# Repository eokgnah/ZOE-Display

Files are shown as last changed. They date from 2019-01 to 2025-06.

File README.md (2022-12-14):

# ZOE CAN ESP32

Bei diesem Projekt handelt es sich um eine Display-Platine zum Auslesen von Fahrzeugdaten (z.B. State of Health, Ladeleistung, Reifendruck) für die Renault ZOE Phase 1 (Q210, R210, R240, Q90, R90, R110, nur bis 2019).

Das Display wird mittels einer 3D-druckbaren Halterung in die Ablage unterhalb des R-Link eingelegt und über den direkt darunterliegenden OBD-Port an den CAN-Bus des Fahrzeugs angeschlossen. Es verwendet einen ESP32-Mikrocontroller mit WLAN-Funktionalität und kann per Webbrowser konfiguriert werden. 

Weitere Informationen und Bilder gibt es im GoingElectric-Forum unter https://www.goingelectric.de/forum/viewtopic.php?t=37914

Platine V5 wird über den USB-Port des R-Link mit Strom versorgt. 

Bei den Platinen V7 und V8 erfolgt die Stromversorgung über den OBD-Port. Hierbei schaltet sich die Platine beim Aufschließen des Fahrzeugs oder Starten eines Ladevorgangs automatisch ein (sobald der CAN-Bus aktiv ist). Nach Abschließen des Fahrzeugs bzw. Beendigung des Ladevorgangs kann sich das Display nach einer konfigurierbaren Zeitdauer auch selbst wieder ausschalten.
Optional kann eine USB-Buchse integriert werden, über welche beispielsweise Mobilgeräte aufgeladen werden können.

Für die Platine V8 existiert eine ausführliche Lötanleitung unter https://github.com/eokgnah/ZOE-Display/blob/master/Platine%20V8/README.md.
Der Aufbau sollte damit auch für Unerfahrene kein allzu großes Problem darstellen.

<pre>
!!!!!!!!!!!!!!!!!!!!!!!!!!!!!!!!!!!!!!!!!!!!!!!!!!!!!!!!!!!!!!!!!!
!!!! OHNE GEWÄHR, ALLES AUF EIGENE GEFAHR, NUR ZU TESTZWECKEN !!!!
!!!!!!!!!!!!!!!!!!!!!!!!!!!!!!!!!!!!!!!!!!!!!!!!!!!!!!!!!!!!!!!!!!
</pre>

## Verwendete Bauteile

- ESP32-Development-Board 38-Pin-Variante (z.B. https://www.berrybase.de/esp32-nodemcu-development-board oder https://www.ebay.de/itm/122795614934 oder https://www.amazon.de/gp/product/B071P98VTG)
- 2,8 Zoll 240 x 320 SPI TFT Panel resistiver Touchscreen (mit Display-Treiber ILI9341, z.B. https://www.ebay.de/itm/284811606229 oder https://www.amazon.de/dp/product/B082QVKT7M oder https://de.aliexpress.com/item/1005002233178546.html [Variante TL9341])
- alternativ mit kapazitivem Touchscreen (Adafruit 1947 mit Display-Treiber ILI9341, z.B. https://www.exp-tech.de/displays/tft/5430/adafruit-2.8-tft-touch-shield-for-arduino-w/capacitive-touch oder https://www.amazon.de/gp/product/B00R3R65C0/ oder https://www.mouser.de/ProductDetail/Adafruit/1947?qs=GURawfaeGuArmJSJoJoDJA%3D%3D)
- SD-Karte (bei resistivem Touchscreen) bzw. microSD-Karte (bei kapazitivem Touchscreen)
- optional GPS-Modul NEO-6M (z.B. https://www.berrybase.de/u-blox-neo-6m-gps-ttl-empfaenger-inkl.-antenne oder https://www.amazon.de/gp/product/B088LR3488 oder https://www.ebay.de/itm/265640015319)
- Kleinteile (siehe Ordner zur jeweiligen Platinen-Version)

## Verbindungen mit resistivem Touchscreen
<pre>
ESP32 Dev Board Pinout

Wohin           Bezeich.       ESP32 Pins       Bezeich.    Wohin

                            3V3         GND
                            EN          G23     MOSI        Display,Touch,SD
                ST          G36         G22
                            G39         G1      (TX)
                            G34         G3      (RX)
                (CAN2 RX)   G35         G21     CS          Touch
                (CAN2 TX)   G32         GND
                HR          G33         G19     MISO        Display,Touch,SD
                            G25         G18     SCLK        Display,Touch,SD
GPS-Modul       GPS TX      G26         G5 
GPS-Modul       GPS RX      G27         G17     CAN TX      OBD-Anschluss
BUZZER+                     G14         G16     CAN RX      OBD-Anschluss
                POWER OFF   G12         G4      RST         Display
                            GND         G0      (BOOT)
SD              CS          G13         G2      DC          Display
                (Flash)     G9          G15     CS          Display
                (Flash)     G10         G8      (Flash)
                (Flash)     G11         G7      (Flash)
                            5V          G6      (Flash)
</pre>                    
RX und TX gibt den Pin an, mit dem es verbunden werden muss. GPS TX muss also auf den Pin
TX am GPS Modul! 

CAN2 ist derzeit experimentell. 

ST = Screen Turn, ST=1 (verbinden mit 3V3) -> Bildschirm um 180 Grad gedreht

HR = Helligkeitsregelung, kann einen Transistor ansteuern, über den die LED-Hintergrundbeleuchtung des Displays gedimmt werden kann.

POWER OFF = Ausschalt-Pin für die Stromversorgung über den OBD-Port

## Verbindungen mit kapazitivem Touchscreen
<pre>
ESP32 Dev Board Pinout

Wohin           Bezeich.       ESP32 Pins       Bezeich.    Wohin

                            3V3         GND
                            EN          G23     SPI MOSI    Display
                ST          G36         G22     I²C SCL     Display
                            G39         G1      (TX)
                            G34         G3      (RX)
                (CAN2 RX)   G35         G21 
                (CAN2 TX)   G32         GND
Display         HR          G33         G19     SPI MISO    Display
Display         I²C SDA     G25         G18     SPI SCLK    Display
GPS-Modul       GPS TX      G26         G5
GPS-Modul       GPS RX      G27         G17     CAN TX      OBD-Anschluss
BUZZER+                     G14         G16     CAN RX      OBD-Anschluss
                POWER OFF   G12         G4      RST         Display
                            GND         G0      (BOOT)
Display         CARDCS      G13         G2      DC          Display
                (Flash)     G9          G15     CS          Display
                (Flash)     G10         G8      (Flash)
                (Flash)     G11         G7      (Flash)
                            5V          G6      (Flash)
</pre>                    
RX und TX gibt den Pin an, mit dem es verbunden werden muss. GPS TX muss also auf den Pin
TX am GPS Modul! 

CAN2 ist derzeit experimentell. 

ST = Screen Turn, ST=1 (verbinden mit 3V3) -> Bildschirm um 180 Grad gedreht

HR = Helligkeitsregelung, an Pin GPIO33 liegt ein PWM Signal an, welches über Pin D5 am Display
(neben CARDCS) die Regelung der Displayhelligkeit erlaubt. Achtung: Die Lötbrücke #5 auf der 
Displayplatine muss hierfür gesetzt werden.

POWER OFF = Ausschalt-Pin für die Stromversorgung über den OBD-Port
                    
## Allgemein
-  Beim Betrieb des resistiven Displays mit 3,3 V sollte der Jumper J1 am Display gesetzt (verbunden) werden (Ausschalten
des Spannungsreglers des Displays, sonst sinken die 3,3 V auf irgendwas unter 3 V). Der Touch IRQ Pin bleibt leer.
- Das Display mit kapazitivem Touchscreen erhält 5 V Versorgungsspannung. Falls das verwendete Display keine IOREF-Lötbrücke besitzt bzw. diese auf 5 V gesetzt wurde, muss eine geeignete Maßnahme vorgesehen werden, um die Spannungspegel am I²C-Bus auf max. 3,3 V zu begrenzen (das Display zieht die Leitungen nämlich mit 10-kΩ-Pull-Up-Widerständen gegen 5 V).

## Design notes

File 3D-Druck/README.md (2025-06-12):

Die Versionen V6 sind für die Platine V5, mit Loch für ein USB-Kabel zur Stromversorgung.
Die Versionen V7 sind für die Platinen V7 oder V8, ohne selbiges Loch.

Damit das Teil in der Ablage der ZOE gut hält und nicht herumrutscht, sollte umlaufend ein ca. 5 x 5 mm dicker Schaumstoffstreifen angeklebt werden.

Zum Drucken sollte ein Material mit guter Hitzebeständigkeit verwendet werden, z.B. ABS. Meine aus PLA gedruckte Version hatte sich nach einem Jahr im Auto stark verformt :-)

Hier einige 3D-Druck-Dienstleister:
- https://www.3ddesign24.de/
- https://fdm-druckservice.de
- https://3-dreams.de

Aktuell habe ich noch zwei 3D-gedruckte Teile für das resistive Display aus grauem ABS abzugeben, welche ich bei 3ddesign24.de bestellt habe. Schaumstoffstreifen für den sicheren Halt in der ZOE habe ich bereits rundherum angebracht. Bei Interesse gerne schreiben an kepppfeff@outlook.de.

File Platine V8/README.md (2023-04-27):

# Platine V8 — Lötanleitung

von Michi (Kontakt: kepppfeff@outlook.de oder im GoingElectric-Forum: kepppfeff-ZOE)

<pre>
!!!!!!!!!!!!!!!!!!!!!!!!!!!!!!!!!!!!!!!!!!!!!!!!!!!!!!!!!!!!!!!!!!
!!!! OHNE GEWÄHR, ALLES AUF EIGENE GEFAHR, NUR ZU TESTZWECKEN !!!!
!!!!!!!!!!!!!!!!!!!!!!!!!!!!!!!!!!!!!!!!!!!!!!!!!!!!!!!!!!!!!!!!!!
</pre>

## Benötigte Bauteile

Zusätzlich zu den unter https://github.com/eokgnah/ZOE-Display/blob/master/README.md aufgelisteten Hauptkomponenten und dem 3D-Druck werden die folgenden Bauteile benötigt. 

#### Module & Halbleiter
- U2: Spannungsregler OKI-78SR-5/1.5-W36-C oder vergleichbar (Ausgang 5 V, 1500...2000 mA)
  - Bezugsquellen: z.B. https://www.tme.eu/de/details/amsr2-7805jz/dc-dc-wandler/aimtec/ oder https://www.reichelt.de/dc-dc-wandler-oki-78sr-8-w-5-v-1500-ma-sil-single-oki515w36c-p140735.html oder https://www.voelkner.de/products/1038830/
  - Falls keine USB-Buchse an die Platine angeschlossen werden soll, kann stattdessen auch ein schwächerer (günstigerer) Spannungsregler verwendet werden, z.B. LC78_05-0.5 oder vergleichbar (Ausgang 5 V, 500 mA)
- U3: Spannungsregler LC78_03-0.5 oder LMO78_03-0.5 oder vergleichbar (Ausgang 3,3 V, 500 mA)
  - Bezugsquellen: z.B. https://www.tme.eu/de/details/amsro-783.3-nz/dc-dc-wandler/aimtec/ oder https://www.reichelt.de/dc-dc-wandler-1-65-w-3-3-v-500-ma-sil-lmo78-03-0-5-p242833.html oder https://www.voelkner.de/products/1038822/
  - Stattdessen kann auch der interne Spannungsregler des ESP32-Boards verwendet werden, dieser ist jedoch nicht so effizient und sorgt für zusätzliche Aufheizung des Mikrocontrollers, was evtl. dessen Lebensdauer verringert.
- Q1: P-Kanal-MOSFET IRFU9024N
- IC4: CAN-Transceiver MCP2562 (DIP8)
- D3, D4: Schottky-Dioden 1N5817
- T1: NPN-Transistor BC547C (nur bei Verwendung des kapazitiven Displays)
- T4: PNP-Transistor BC327-25
- T5, T6: NPN-Transistoren BC547C

#### Passive Bauelemente
- R1: Widerstand 100 kΩ ± 50 % (nur bei Verwendung des kapazitiven Displays)
- R3: Widerstand 1,5 kΩ ± 5 % (nur bei Verwendung des resistiven Displays mit eingebautem Transistor, siehe weiter unten) bzw. Widerstand 5,1 Ω ± 5 % (nur bei Verwendung des resistiven Displays ohne eingebauten Transistor, siehe weiter unten)
- R4: Widerstand 15 kΩ ± 5 % (nur bei Verwendung des kapazitiven Displays der alten Version, siehe weiter unten)
- R5: Widerstand 120 Ω ± 10 %
- R6: Widerstand 15 kΩ ± 5 %
- R7: Widerstand 15 kΩ ± 5 % (nur bei Verwendung des kapazitiven Displays der alten Version, siehe weiter unten)
- R8: Widerstand 100 kΩ ± 5 %
- R9: Widerstand 470 kΩ ± 10 %
- R10, R11: Widerstände 1,2 MΩ ± 5 %
- R12: Widerstand 470 kΩ ± 5 %
- R13: Widerstand 47 kΩ ± 5 %
- C1: Elektrolyt-Kondensator 10 μF, min. 10 V
- C2, C3, C4: Keramik-Kondensatoren 100 nF
- C5: Elektrolyt-Kondensator 10 μF, min. 25 V
- C6: Elektrolyt-Kondensator 22 μF, min. 6,3 V

#### Steckverbinder & Elektromechanik
- OBD-Stecker (z.B. https://kds-online.de/de/obd-minitools-modular-system-stecker-e.html oder https://www.tme.eu/de/details/a-obd-e2/gehause-sonstiges-zubehor/minitools/sep-a-obd-e2/)
- Piezo-Summer, mit Kabeln oder für Printmontage (RM 7,6 mm)
- IC-Sockel DIP8 (für MCP2562)
- USB-Buchse (optional)
- Schraubklemmblock 3-polig (RM 5 mm) für Stromversorgung (12 V Eingang, 5 V Ausgang)
- Schraubklemmblock 2-polig (RM 5 mm) für CAN-Bus
- Kabel zum Anschluss von OBD-Stecker und ggf. USB-Buchse
- Stiftleisten (für GPS-Modul, resistives Display und ggf. als Abstandshalter)

## Grundlegendes Vorgehen

Wer bereits Platinen bestückt hat, kann diesen Abschnitt gerne überspringen ;-)

Zum Zusammenbau des ZOE-Displays benötigt ihr Folgendes:
- Lötkolben und Lötzinn, Lötspitzen-Reinigungstool (feuchter Schwamm, Spiralwolle etc.)
- Seitenschneider bzw. Vornschneider
- Spitzzange
- Abisolierzange
- Schlitz-Schraubendreher
- Heißklebepistole und -sticks, alternativ 2-Komponenten-Kleber oder ähnliches
- Eventuell (falls ihr etwas falsch verlötet habt): Entlötsaugpumpe, Entlötlitze etc.

Bei dieser Platine werden alle Bauteile in Durchsteckmontage (Printmontage) bestückt. Die grundlegende Vorgehensweise, um ein Bauteil einzulöten, ist Folgende:

1. Anschlussdrähte des Bauteils zurechtbiegen (falls nötig).
2. Bauteil von der Seite der Platine, auf der der Bestückungsdruck für das Bauteil angebracht ist, durch die entsprechenden Kontaktlöcher stecken.
3. Platine umdrehen und die herausragenden Drähte (bzw. Metallstifte) nacheinander mit den Leiterbahnen verlöten. Zum Löten sollte man in der Regel zuerst den Lötkolben an die beiden zu verlötenden Metallteile halten (hier Draht und Leiterplattenkontakt), sodass die Lötspitze *beide* Teile erhitzt. Direkt anschließend gibt man das Lötzinn hinzu, welches sich nun kegelförmig (nicht kugelförmig :D) um den Draht verteilen sollte. 
4. Alle überstehenden Drähte abschneiden, und zwar möglichst direkt an der Lötstelle.

Hierbei kann man entweder alle Bauteile einzeln nacheinander durchstecken und verlöten oder auch mehrere auf einmal. Damit die Bauteile während des Lötens nicht nach unten aus der Platine herausrutschen können, macht es Sinn, mit den flachsten Bauteilen anzufangen und sich nach und nach zu den höchsten Bauteilen vorzuarbeiten. Im Idealfall liegt die Platine dann immer auf dem Bauteil auf, welches als Nächstes angelötet werden soll. 

Wenn ihr noch nie Bauteile auf eine Platine gelötet habt, ist es sicherlich hilfreich, vorher mal ein entsprechendes Tutorial-Video z.B. auf Youtube anzuschauen.

## Hinweise zum resistiven Touchscreen

Bei Verwendung des Displays mit resistivem Touchscreen werden die Widerstände R1, R4 und R7 sowie der Transistor T1 nicht benötigt.

Falls ihr das Display mit resistivem Touchscreen verwendet, solltet ihr zunächst prüfen, ob dieses einen eingebauten Transistor für die LED-Hintergrundbeleuchtung eingebaut hat oder nicht. Nur wenn ein Transistor eingebaut ist, könnt ihr die Helligkeit des Displays steuern.
Von der Versionsbezeichnung des Displays hängt dies scheinbar nicht ab; ich habe schon Bilder von V1.1 und V1.2 jeweils sowohl mit und ohne Transistor gesehen! Ihr müsst also tatsächlich den Transistor auf der Display-Platine suchen. Es handelt sich um ein kleines schwarzes Bauteil mit drei Pins, welches auf der Platine mit **Q1** beschriftet sein muss (es gibt eventuell ein gleich aussehendes Bauteil, welches anders beschriftet ist, das ist aber kein Transistor, sondern ein Spannungsregler). 
- Falls euer Display *zwei* kleine schwarze Bauteile mit je drei Pins hat, von denen eines mit U1 und eines mit Q1 beschriftet ist, dann habt ihr ein Display *mit* eingebautem Transistor. **In diesem Fall muss für R3 ein 1,5-kΩ-Widerstand eingesetzt werden. Außerdem sollte die Lötbrücke SJ5 gesetzt werden, damit die Display-Helligkeit vom ESP32 gesteuert werden kann.**
- Falls euer Display nur *ein* kleines schwarzes Bauteil mit drei Pins hat, dann hat das Display *keinen* Transistor eingebaut. **In diesem Fall muss für R3 ein 5,1-Ω-Widerstand eingesetzt werden (anders als auf dem Bestückungsdruck angegeben!). Die Lötbrücke SJ5 muss offen bleiben, da sonst der ESP32 Schaden nehmen kann!**

In der Regel müsst ihr auf euer Display noch eine 4-polige Stiftleiste für die Anschlüsse der SD-Karte einlöten. Hier darauf achten, dass ihr diese möglichst gerade montiert, damit das Display später perfekt auf die Platine passt. Am Besten gelingt dies, wenn ihr das Display zum Anlöten der 4-polige Stiftleiste lose in die entsprechenden Kontaktlöcher der (noch unbestückten) Platine legt.

Das resistive Display besitzt zudem eine Lötbrücke (J1), die ggf. gesetzt werden muss. Hierzu bitte den Abschnitt „Hinweise zu den Lötbrücken zur Auswahl der Stromversorgung“ beachten.

## Hinweise zum kapazitiven Touchscreen

Bei Verwendung des Displays mit kapazitivem Touchscreen wird der Widerstand R3 nicht benötigt.

Falls ihr das Display mit kapazitivem Touchscreen verwendet, solltet ihr zunächst prüfen, ob ihr die alte oder die neue Version des Displays besitzt. Kleine Anmerkung am Rande: Auf den beiden folgenden Fotos wurde jeweils rechts die 6-polige ISP-Buchse abgelötet, dies ist jedoch bei der Platine V8 nicht erforderlich!

### Alte Version
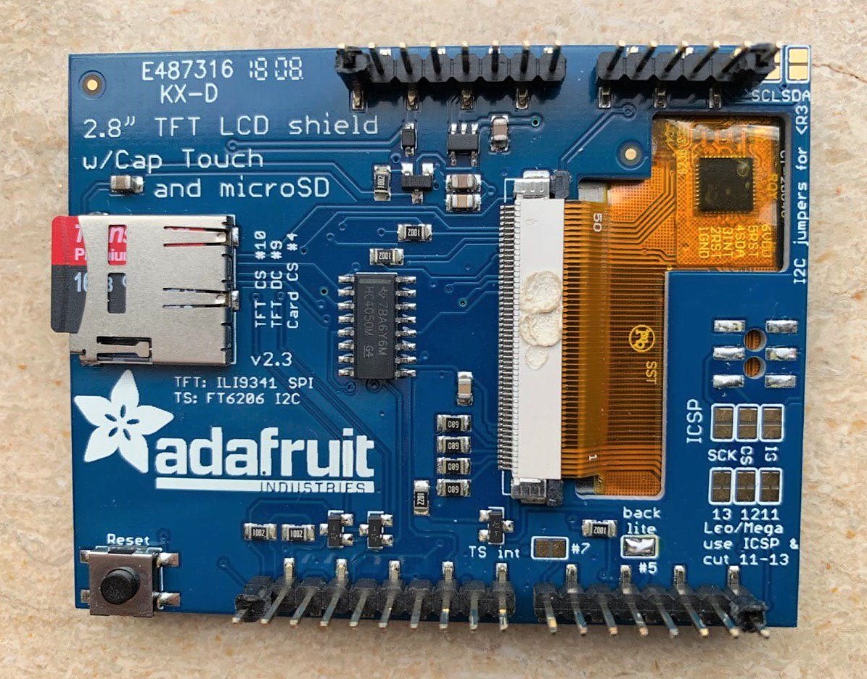
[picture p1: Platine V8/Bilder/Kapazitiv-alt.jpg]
Alte Version

Hier müsst ihr lediglich die Lötbrücke „backlight #5“ setzen, wie im Foto zu sehen, damit die LED-Hintergrundbeleuchtung gedimmt werden kann. Die Lötbrücken „13“, „12“ und „11“ sind bei dieser Version bereits standardmäßig (über feine Leiterbahnen) gesetzt.

**Bei der Bestückung der Platine sind die beiden 15-kΩ-Widerstände R4 und R7 zwingend erforderlich, da ohne diese der ESP32 eine zu hohe Spannung vom Display abbekommt.**

### Neue Version
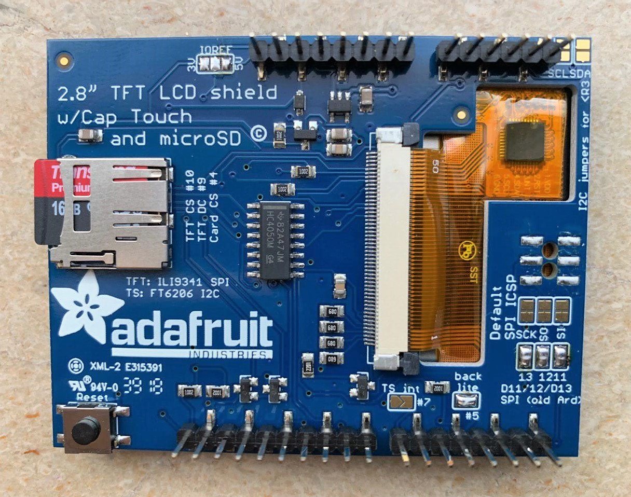
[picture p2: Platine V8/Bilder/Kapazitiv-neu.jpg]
Neue Version

Wie man sieht, gibt es hier die zusätzliche Lötbrücke IOREF. Diese müsst ihr (anders als im Foto!) auf 3,3 V setzen, also das mittlere und das linke (mit „3V“ beschriftete) Pad mit einem Tropfen Lötzinn verbinden. 

**Bei der Bestückung der Platine sollten dann die beiden 15-kΩ-Widerstände R4 und R7 weggelassen werden.**

Außerdem müsst ihr die Lötbrücken „backlight #5“, „13“, „12“ und „11“ setzen (wie im Foto zu sehen).

## Hinweise zu den Lötbrücken zur Auswahl der Stromversorgung

Der 3,3-V-Spannungsregler **U3** (LC78_03-0.5 oder ähnlich) ist nicht unbedingt erforderlich, da alternativ auch der interne (lineare) Spannungsregler des ESP32 verwendet werden kann. Zur Auswahl zwischen diesen beiden Varianten dienen die Lötbrücken SJ2, SJ3 und SJ4.

### Falls die Platine mit Spannungsregler U3 bestückt wird, ...

... werden ESP32, GPS-Modul und resistives Display vom Spannungsregler U3 mit 3,3 V versorgt. 

**Hierzu muss die Lötbrücke SJ4 gesetzt werden. Bei Verwendung des resistiven Displays muss zusätzlich dessen Lötbrücke J1 gesetzt werden.**

Wenn die Platine nur über den USB-Port des ESP32 betrieben wird (z.B. zum Flashen), ist das kapazitive Display bei dieser Schaltungsvariante nicht in Betrieb! Wer dies ändern möchte, kann zusätzlich die Lötbrücke SJ2 setzen, allerdings wird dadurch bei Versorgung über den OBD-Port die Spannungswandlung ineffizienter, da der interne Spannungsregler des ESP32 ständig „mitläuft“.

### Falls der Spannungsregler U3 weggelassen wird, ...

... werden ESP32, GPS-Modul und resistives Display vom Spannungsregler U2 mit 5 V versorgt. Alle drei nutzen dann ihre internen linearen Spannungsregler, um die Spannungsdifferenz zu verbraten. 

**Hierzu müssen die Lötbrücken SJ2 und SJ3 gesetzt werden. Bei Verwendung des resistiven Displays muss dessen Lötbrücke J1 offen bleiben.**

## Platine löten
#### Schritt 1: Lötbrücken setzen

Als erstes solltet ihr alle benötigten Lötbrücken setzen. 

- SJ1 bestimmt über die Ausrichtung des Bildschirms. Bei Verwendung des 3D-gedruckten ZOE-Einlegers sollte diese Lötbrücke für das resistive Display normalerweise auf die Seite mit dem „S“ und für das kapazitive Display auf die Seite mit der „1“ gesetzt werden. An diese Lötbrücke kommt man auch später noch ganz gut dran, sodass es kein Problem ist, wenn sie falsch gesetzt wurde.
- Wie ihr SJ2, SJ3 und SJ4 setzen müsst, findet ihr unter „Hinweise zu den Lötbrücken zur Auswahl der Stromversorgung“.
- SJ5 sollte nur bei Verwendung eines resistiven Displays mit eingebautem Transistor gesetzt werden.

#### Schritt 2: Widerstände und Dioden

Als nächstes kommen die flachen Bauteile dran. Bei Widerständen ist die Polarität egal, bei den Dioden ist der Strich, welcher den Minuspol kennzeichnet, auf dem Bestückungsdruck eingezeichnet. 

#### Schritt 3: IC-Sockel

Damit der CAN-Transceiver-IC (IC4) nicht durch die Hitze Schaden nimmt, wird er nicht auf die Platine gelötet, sondern nur ein passender Sockel, in den der IC später eingesteckt wird. Die Einbaurichtung des ICs kann über eine einseitige Einkerbung kontrolliert werden, welche auf dem Bestückungsdruck eingezeichnet ist.

#### Schritt 4: Keramik-Kondensatoren

Nun sind C2, C3 und C4 an der Reihe. Es können Keramik-Kondensatoren mit 2,5 mm oder 5 mm Rastermaß verwendet werden. Die Polarität ist egal. 

#### Schritt 5: Piezo-Summer

Falls ein Piezo-Summer für Printmontage verbaut wird, sollte dieser je nach Abmessungen jetzt oder etwas später eingelötet werden. Bei einigen Piezo-Summern muss die Polarität beachtet werden (z.B. wenn die Beinchen verschieden lang sind, das längere ist dann Plus), bei anderen nicht.

#### Schritt 6: Stiftleiste für GPS-Modul

Als Nächstes wird eine Stiftleiste eingelötet, auf die später das GPS-Modul montiert werden kann. Das GPS-Modul selbst sollte jetzt noch nicht mit angelötet werden, da es die Anschlüsse für das kapazitive Display teilweise verdecken würde. Je nach GPS-Modul wird eine Stiftleiste mit 4 oder 5 Pins benötigt. Es empfiehlt sich, die Metallstifte etwas zu kürzen, damit sie später nicht so weit herausstehen.

Inzwischen sollte die Platine ungefähr so aussehen:

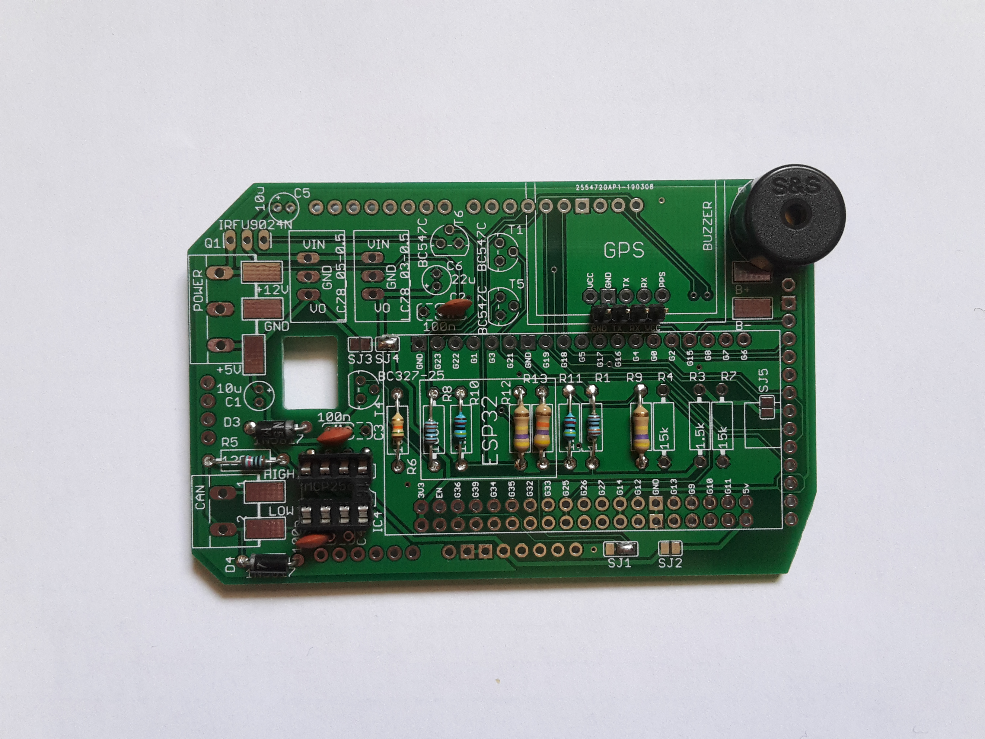
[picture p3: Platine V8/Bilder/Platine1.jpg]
Platine


#### Schritt 7: Transistoren

Jetzt sind die bipolaren Transistoren T1, T4, T5, T6 und der MOSFET Q1 an der Reihe. Bei den bipolaren Transistoren muss jeweils der mittlere Pin vorsichtig etwas zurechtgebogen werden. Die Einbaurichtung dürfte selbsterklärend sein. Der MOSFET muss so herum eingebaut werden, dass die Beschriftung zum Rand der Platine zeigt (und die Metallfläche entsprechend in Richtung der Kabelanschlüsse). 

#### Schritt 8: Schraubklemmblöcke

Nun werden die 3-polige Schraubklemme für die Stromversorgung und die 2-polige Schraubklemme für den CAN-Bus eingelötet.

#### Schritt 9: ESP32

Die Platine ist kompatibel zu zwei verschieden großen ESP32-Boards (mit dem selben Pinout), daher ist die eine Lochreihe doppelt vorhanden. 

Bei günstigen ESP32-Boards sind oft die Stiftleisten nicht ganz gerade eingelötet, dann müsst ihr diese noch etwas zurechtbiegen, um sie in die Kontaktlöcher der Platine zu bekommen.

Damit der ESP32 nachher in der perfekten Höhe (und gerade) montiert ist, bietet es sich an, auf die vier äußersten Pins jeweils als Abstandshalter ein Plastikteil einer Stiftleiste draufzuschieben. Hierzu aus einer vierpoligen Stiftleiste alle Metallstifte herausziehen und anschließend das Plastikteil in seine vier Einzelteile zerbrechen. Am Ende sollte es dann so aussehen (hier sind zusätzlich die Abstandshalter des resistiven Touchdisplays zu sehen, beim kapazitiven werden hingegen keine benötigt):

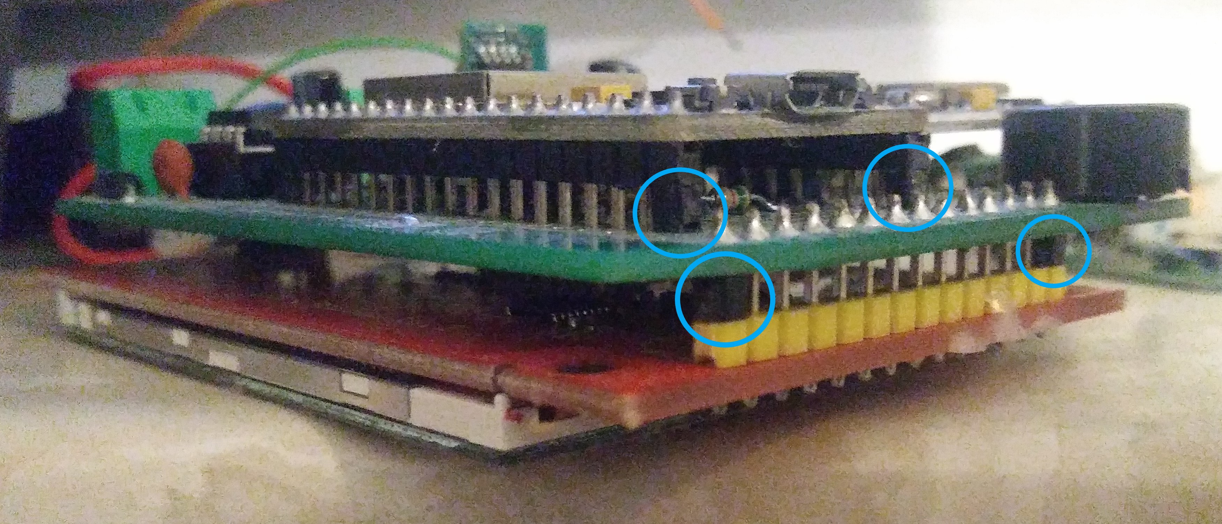
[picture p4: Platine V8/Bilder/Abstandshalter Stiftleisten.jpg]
Abstandshalter


#### Schritt 10: 3,3-V-Spannungsregler

Der 3,3-V-Spannungsregler kommt in das mit „LC78_**03**-0.5“ beschriftete Rechteck. Einbaurichtung beachten! In der Regel sollte die Bauteilbeschriftung in Richtung des POWER-Schraubklemmblocks zeigen. Bei Unsicherheit am Besten im Datenblatt nachschauen, auf der Platine ist der Eingang mit VIN und der Ausgang mit VO beschriftet. 
Falls der Spannungsregler LMO78_03-0.5 verwendet wird (wie im gleich folgenden Foto), sollte dieser eventuell ein wenig gekippt eingebaut werden, da er sonst etwas zu weit in Richtung des Kondensators C6 übersteht, sodass dieser nicht mehr richtig passt.

#### Schritt 11: Elektrolyt-Kondensatoren

Bei den Elkos (C1, C5 und C6) muss auf die Polarität geachtet werden. Der Pluspol ist durch einen längeren Draht, der Minuspol durch einen weißen Strich auf dem Gehäuse gekennzeichnet.

#### Schritt 12: 5-V-Spannungsregler

Der 5-V-Spannungsregler gehört in das mit „LC78_**05**-0.5“ beschriftete Rechteck. Einbaurichtung beachten! Bei Unsicherheit am Besten im Datenblatt nachschauen, auf der Platine ist der Eingang mit VIN und der Ausgang mit VO beschriftet.

Anschließend sollte die Platine ungefähr so aussehen:

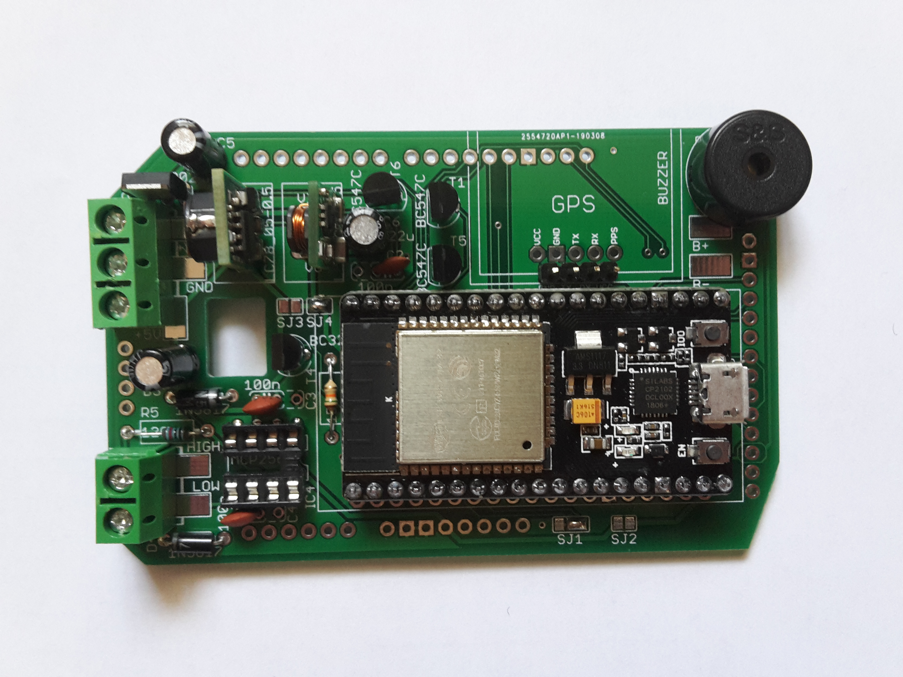
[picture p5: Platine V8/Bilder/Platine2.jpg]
Platine


#### Schritt 13: Display

Bevor ihr Display und Platine zusammenfügt, kontrolliert nochmal, ob alle Lötstellen gut aussehen und ob ihr am Display alle erforderlichen Lötbrücken gesetzt habt, denn ihr kommt anschließend nicht mehr dran! 

Beim kapazitiven Display empfehle ich, dieses erstmal in den 3D-gedruckten Einleger zu setzen (microSD-Karte einlegen und Schutzfolie abziehen!), anschließend die Platine darauf zu platzieren und erst dann, im „lose eingebauten Zustand“, beides zu verlöten. 

Beim resistiven Display ist dieses Vorgehen nicht erforderlich, hier bietet es sich stattdessen an, wieder vier Plastikteile einer Stiftleiste als Abstandshalter zu nutzen. Achtet darauf, dass der SD-Karten-Halter nicht mit von der Platine abstehenden Drähten in Berührung kommt. Zur Sicherheit bietet es sich an, den SD-Karten-Halter mit Kaptonband, Tesafilm oder ähnlichem zu überkleben. 

#### Schritt 14: GPS-Modul

Als Nächstes wird das GPS-Modul auf die zuvor eingelötete Stiftleiste gelötet.

#### Schritt 15: IC einsetzen

Zu guter Letzt wird der CAN-Transceiver-IC in den zuvor eingelöteten Sockel gesteckt. Ausrichtung beachten! Bei „fabrikfrischen“ ICs müssen vorher meist noch die Beinchen etwas nach innen gebogen werden. 

## Verkabelung

Die Drähte zur USB-Buchse, zum OBD-Stecker und zum Piezo-Summer (falls einer mit Kabeln verwendet wird) können auf drei verschiedene Arten an der Platine angeschlossen werden: Durch Anschrauben in angelötete Schraubklemmblöcke, über die SMD-Lötpads oder durch direktes Einlöten der Kabel in die Löcher für die Schraubklemmblöcke. 

Die Beschriftung der Anschlüsse befindet sich jeweils an den SMD-Lötpads, die direkt an die zugehörigen Schraubklemmen angrenzen.

#### USB-Buchse

Um die USB-Buchse in den 3D-gedruckten Einleger zu bekommen, müssen zunächst die beiden Montagepins des Buchsengehäuses etwas gekürzt werden. Anschließend die vier Anschlusspins (Masse, D+, D- und +5 V) nach hinten umbiegen und darauf achten, dass sie nicht mit dem Buchsengehäuse in Berührung kommen. 

An Masse (GND) und +5 V lötet ihr Drähte an, die dann an der Platine angeschlossen werden können. Achtet darauf, dass durch das Lötzinn keine Verbindung mit dem Buchsengehäuse hergestellt wird.

Die beiden Datenleitungen (die mittleren Pins) können im einfachsten Fall kurzgeschlossen werden, dies entspricht der EU-standardisierten Signalisierung eines USB-Ladegeräts. Hierzu einfach die beiden Drähte etwas zur Mitte biegen und mit einem Tropfen Lötzinn verbinden (wieder darf keine Verbindung zum Buchsengehäuse entstehen). Manche USB-Geräte akzeptieren diese Signalisierung allerdings nicht und laden nur langsam. Um die USB-Buchse für solche Geräte kompatibel zu machen, müsst ihr eventuell statt der Kurzschlussmethode bestimmte Spannungen mittels Widerständen an die Datenleitungen anlegen. Mehr Infos dazu findet ihr z.B. hier: http://dh2mic.darc.de/files/usb-adapter-v12.pdf

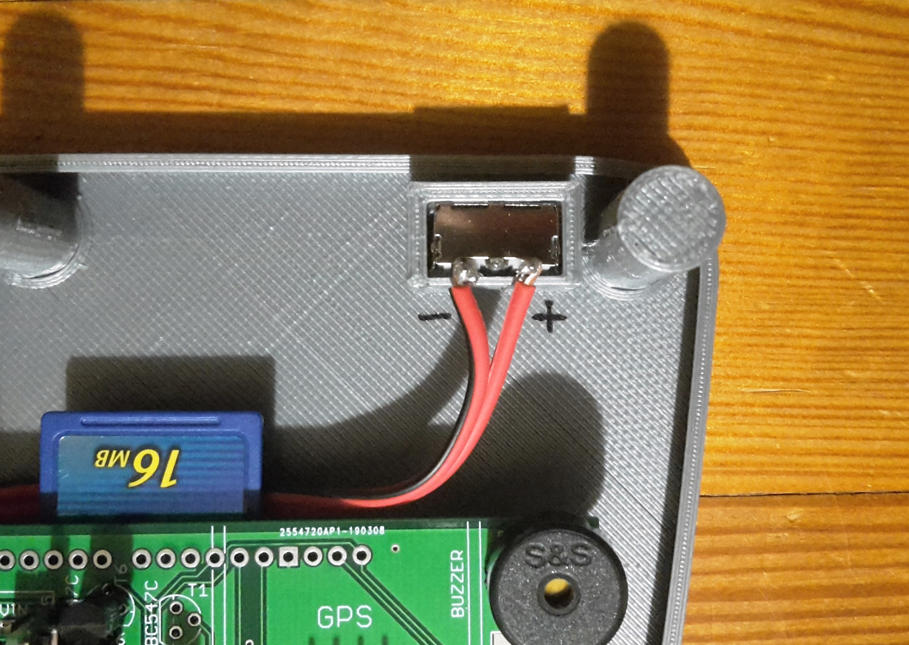
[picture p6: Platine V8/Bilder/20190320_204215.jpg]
USB-Buchse


Zum Schluss noch alles mit Heißkleber, 2-Komponentenkleber o.ä. versiegeln, damit kein Kurzschluss entstehen kann und die USB-Buchse nicht herausrutscht.

#### OBD-Stecker

Die Belegungen einer OBD2-Schnittstelle findet ihr hier: https://commons.wikimedia.org/wiki/File:OBD2-Buchse-Stecker-Belegung.jpg

Vier Pins werden benötigt: Fahrzeugmasse (GND) und +12 V zur Stromversorgung sowie CAN High und CAN Low zur Datenübertragung. 

Achtung: Den Lötkolben nicht zu lange an die Metallstifte des OBD-Steckers halten, da sonst das Plastik drumherum aufweicht, wodurch der Metallstift sich womöglich leicht verdreht oder verschiebt. Alternativ können die Metallstifte zum Anlöten der Drähte aus dem Steckergehäuse herausgenommen und anschließend wieder eingesetzt werden. Die oben verlinkten OBD-Stecker sind nur zusammengesteckt und die Stifte werden von einer eingeklipsten Plastikkappe gehalten.

Wenn ihr den 3D-gedruckten ZOE-Einleger verwendet, müsst ihr die Kontaktstifte des OBD-Steckers zur Seite umbiegen (bzw. die unbenutzten abschneiden oder entfernen), da diese sonst zu weit herausstehen. Das sollte dann etwa so aussehen. 

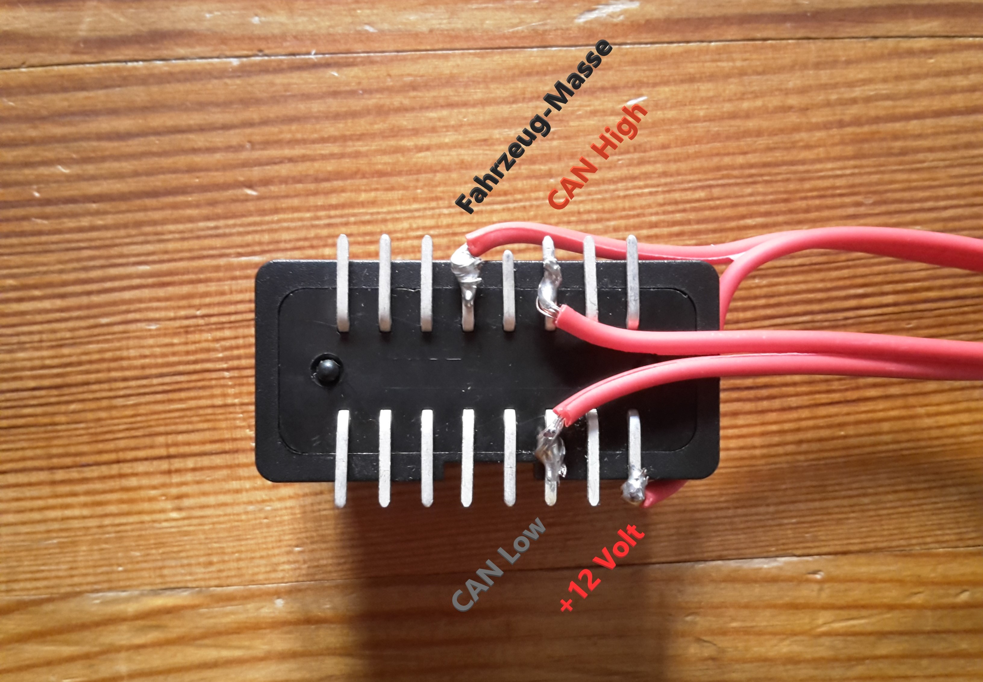
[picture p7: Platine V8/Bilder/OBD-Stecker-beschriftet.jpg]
OBD-Stecker


Anschließend sollten die Lötstellen unbedingt noch z.B. mit Heißkleber oder Schrumpfschläuchen umhüllt werden, damit kein Kurzschluss entstehen kann und die Drähte nicht mit der Zeit (z.B. durch Vibrationen) abbrechen können.

#### Schraubklemmblöcke

Um die Drähte gut in den Schraubklemmblöcken befestigen zu können, sollten die Enden jeweils verdrillt und mit dem Lötkolben verzinnt werden. Wer über das entsprechende Equipment verfügt, kann (und soll) natürlich stattdessen Aderendhülsen verwenden. 

Wer eine USB-Buchse verwendet, muss zwei GND-Drähte in eine Schraubklemme zwängen. Hierzu sollten diese beiden Drähte zusammen verzinnt bzw. zusammen in eine Aderendhülse gecrimpt werden.

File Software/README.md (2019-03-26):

## Software

Anleitung von Erich (eokgnah)

<pre>
!!!!!!!!!!!!!!!!!!!!!!!!!!!!!!!!!!!!!!!!!!!!!!!!!!!!!!!!!!!!!!!!!!
!!!! OHNE GEWÄHR, ALLES AUF EIGENE GEFAHR, NUR ZU TESTZWECKEN !!!!
!!!!!!!!!!!!!!!!!!!!!!!!!!!!!!!!!!!!!!!!!!!!!!!!!!!!!!!!!!!!!!!!!!
</pre>

1. Holt euch die Arduino-IDE: 
https://www.arduino.cc/en/Main/Software

2. Macht die IDE bereit für den ESP32: 
https://randomnerdtutorials.com/installing-the-esp32-board-in-arduino-ide-windows-instructions/

3. Kontrolliert die Einstellungen und installiert auf Eurem neuen ESP32 zum Initialisieren den „bare minimum“-Sketch aus den Beispielen (COM-Port kann bei Euch ggf. ein anderer sein).

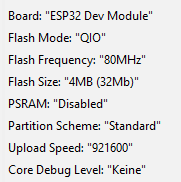
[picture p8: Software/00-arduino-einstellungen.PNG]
Einstellungen der Arduino-IDE


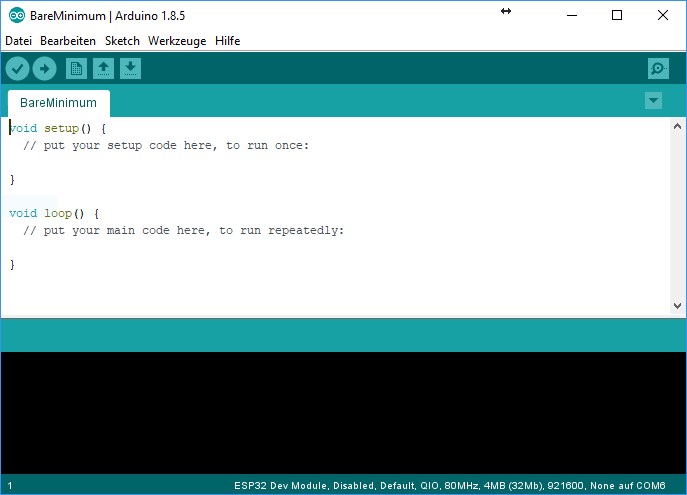
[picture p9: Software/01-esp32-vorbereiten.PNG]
Bare-Minimum-Sketch


Wenn das alles sauber durchgelaufen ist, dann geht es weiter.

4. Holt Euch die „Flash Download Tools (ESP8266 & ESP32)“ von espressif: 
https://www.espressif.com/en/support/download/other-tools

5. Holt Euch das ZOE-Display-Binary (oben in der Ordnerstruktur die entsprechende Datei auswählen oder direkt über den Link https://github.com/eokgnah/ZOE-Display/raw/master/Software/CAN-ESP32.ZOE.esp32-v2.075.bin).

6. Startet die „Flash Download Tools (ESP8266 & ESP32)“, wählt den ESP32 aus und stellt ihn wie folgt ein (COM-Port kann bei Euch ggf. ein anderer sein):

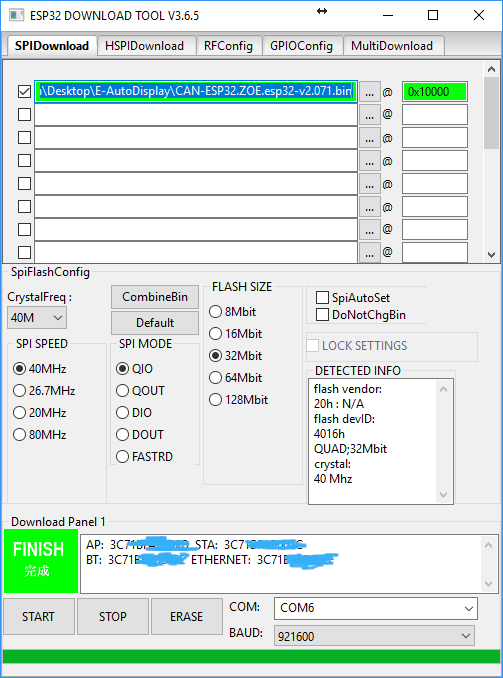
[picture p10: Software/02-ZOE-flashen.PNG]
Einstellungen des Flash Download Tools


7. Auf „START“ drücken und ihn flashen lassen.

8. Wenn er fertig ist, dann könnt Ihr beim ESP mal auf Reset drücken oder ihn kurz vom USB-Strom nehmen, damit er bootet.

9. Es sollte nun ein offener WLAN-Accesspoint (Name so etwas wie „ESP_12BA5C“ oder „ZOE“) bei Euch erschienen sein. 

10. Mit dem WLAN verbinden und auf die IP „192.168.4.1“ mit dem Browser gehen und dann könnt Ihr alles von dort aus über den Browser weiter konfigurieren.

Das alles geht auch nur mit dem ESP32 alleine.
Damit es „sinnvoll“ funktioniert ist es natürlich von Vorteil, wenn Ihr das Display, die SD-Karte, GPS und das CAN-Interface mit anschließt.  

Neuere Updates kommen dann per WLAN „over the air“.
Diese beschriebene Vorgehensweise ist nur ein einziges Mal am Anfang nötig. Danach braucht Ihr keinen PC mehr.

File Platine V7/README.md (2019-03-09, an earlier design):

## Platine V7

von Michi (kepppfeff-ZOE)

<pre>
!!!!!!!!!!!!!!!!!!!!!!!!!!!!!!!!!!!!!!!!!!!!!!!!!!!!!!!!!!!!!!!!!!
!!!! OHNE GEWÄHR, ALLES AUF EIGENE GEFAHR, NUR ZU TESTZWECKEN !!!!
!!!!!!!!!!!!!!!!!!!!!!!!!!!!!!!!!!!!!!!!!!!!!!!!!!!!!!!!!!!!!!!!!!
</pre>

Diese Version funktioniert mit dem kapazitiven Display einwandfrei und passt auch in den 3D-Druck-Einleger.

Das resisitve Display funktioniert technisch auch, allerdings passt die Platine damit nicht in den 3D-Druck-Einleger!

### Allgemeine Hinweise zur Bestückung

- Es können nur Keramikkondensatoren mit 2,5 mm Rastermaß verwendet werden, obwohl auf der Platine jeweils ein zusätzliches Pad für 5 mm Rastermaß vorhanden ist. Denn diese Pads ist nicht angeschlossen!
- Bei den beiden Spannungsreglern ist leider auf dem Bestückungsdruck nicht ersichtlich, welcher wohin gehört. Der 5-V-Spannungsregler muss auf die Seite in Richtung ESP32, der 3,3-V-Spannungsregler auf die Seite in Richtung Anschlussbuchsen.
- Ein 3,3-V-Spannungsregler ist nicht unbedingt erforderlich, da alternativ auch der interne Spannungsregler des ESP32 genutzt werden kann. Falls die Platine mit 3,3-V-Spannungsregler bestückt wird, muss die Lötbrücke SJ4 gesetzt werden; andernfalls müssen die Lötbrücken SJ2 und SJ3 gesetzt werden.
- Der MOSFET (Q1) muss so herum eingebaut werden, dass die Beschriftung in Richtung Spannungsregler zeigt.

### Bei Verwendung des kapazitives Displays

- Die Bauteile R1, R2, R3, R14 sowie T1, T2 und T3 werden nicht benötigt.
- Beim Display müssen die Lötbrücken „backlight“, „13“, „12“ und „11“ gesetzt werden.
- Falls ein Display der neusten Version mit IOREF-Lötbrücke zum Einsatz kommt, sollte diese Lötbrücke auf 3,3 V („3V“) gesetzt werden. Die Widerstände R4 und R7 werden dann nicht benötigt.
- Ich empfehle, das Display erst dann anzulöten, wenn Platine und Display bereits lose im 3D-gedruckten Einleger platziert sind. Ansonsten wird es wahrscheinlich sehr schwierig, diese hineinzubekommen.

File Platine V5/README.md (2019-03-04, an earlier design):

# Platine V5

von erich (eokgnah)

<pre>
!!!!!!!!!!!!!!!!!!!!!!!!!!!!!!!!!!!!!!!!!!!!!!!!!!!!!!!!!!!!!!!!!!
!!!! OHNE GEWÄHR, ALLES AUF EIGENE GEFAHR, NUR ZU TESTZWECKEN !!!!
!!!!!!!!!!!!!!!!!!!!!!!!!!!!!!!!!!!!!!!!!!!!!!!!!!!!!!!!!!!!!!!!!!
</pre>

Im Zip-Archiv befinden sich die Gerber-Dateien zur Herstellung der Platine (z.B. bei https://jlcpcb.com/).

Diese Platine wird über die USB-Buchse des R-Link versorgt. Alternativ kann ein externer Spannungsregler von 12 V auf 5 V genutzt werden, um über die OBD-Buchse versorgt zu werden. In diesem Fall sollte ein manueller Ein-/Ausschalter vorgeschaltet werden, da das Display sonst permanent aktiv wäre und eventuell die 12-V-Batterie zu tief entladen könnte.

Es kann nur das Display mit kapazitivem Touchscreen verwendet werden, da beim resistiven ein Verkabelungsfehler vorliegt.

## Verwendete Bauteile

- ESP32 Development Board (z.B. https://www.amazon.de/gp/product/B071P98VTG)
- Adafruit 2,8 Zoll 240 x 320 TFT Panel mit kapazitivem Touchscreen (ADA1947, https://www.amazon.de/gp/product/B00R3R65C0/)
- CAN-Transceiver-Modul SN65HVD230 (z.B. https://www.amazon.de/gp/product/B00KM6XMXO/)
- Level Shifter 3,3 V <-> 5 V (für SDA und SCL des Displays)
- GPS-Modul (z.B. https://www.amazon.de/gp/product/B01N38EMBF/)
- Kleinteile (CAN-Stecker für OBD Buchse, Piezo-Summer, USB-Kabel und -Buchse, etc.)

## Verbindungsübersicht
<pre>
ESP32 Dev Board Pinout

Wohin       Bezeich.       ESP32 Pins       Bezeich.    Wohin

CAN                     3V3         GND
                        EN          G23     SPI MOSI    Display
                        G36         G22     I2C SCL     Display
                        G39         G1      (TX)
                        G34         G3      (RX)
            (CAN2 RX)   G35         G21 
            (CAN2 TX)   G32         GND
                        G33         G19     SPI MISO    Display
Display     I2C SDA     G25         G18     SPI SCLK    Display
GPS         GPS TX      G26         G5
GPS         GPS RX      G27         G17     CAN TX      CAN Bus
BUZZER+                 G14         G16     CAN RX      CAN Bus 
                        G12         G4      RST         Display
Display,CAN,GPS         GND         G0      (BOOT)
Display     CARDCS      G13         G2      DC          Display
            (Flash)     G9          G15     CS          Display
            (Flash)     G10         G8      (Flash)
            (Flash)     G11         G7      (Flash)
GPS,Display             5V          G6      (Flash)
</pre>                    
Die beiden Leitungen für den I2C Bus (SCL und SDA) müssen über einen Level Shifter geführt 
werden (sowohl ESP32 als auch das Display arbeiten mit Pull Ups auf VCC. Der ESP32 allerdings 
mit 3.3 Volt, das Display mit 5 Volt. Würde nicht ausprobieren wollen, wer ohne Level Shifter gewinnt...)
RX und TX gibt den Pin an, mit dem es verbunden werden muss. GPS TX muss also auf den Pin
TX am GPS Modul! 

CAN2 ist derzeit experimentell. 

## Schaltplan
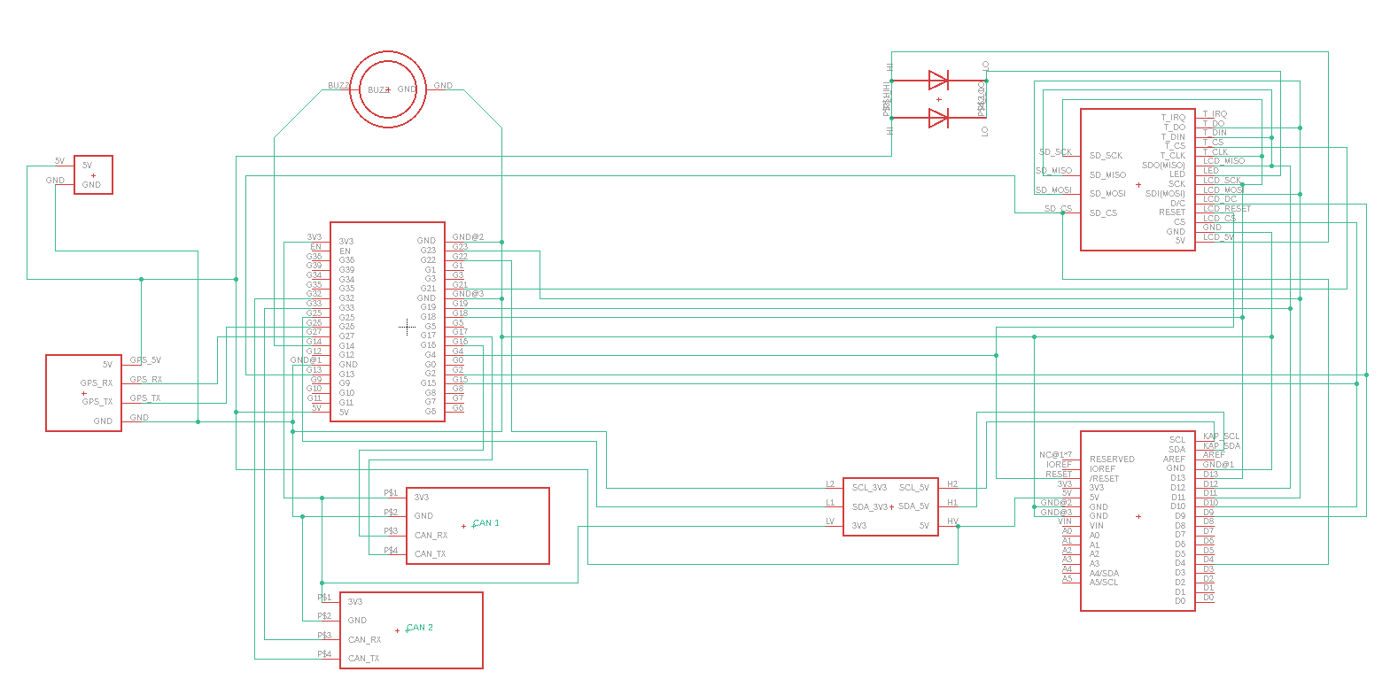
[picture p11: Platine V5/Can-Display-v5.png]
Schaltplan


Rechts unten ist das kapazitive Display. Rechts oben das als Alternative gedachte Display mit resistivem Touchscreen, 
welches aber nicht verwendet werden kann, da ein Verdrahtungsfehler vorliegt! Die beiden Dioden werden somit auch nicht benötigt.

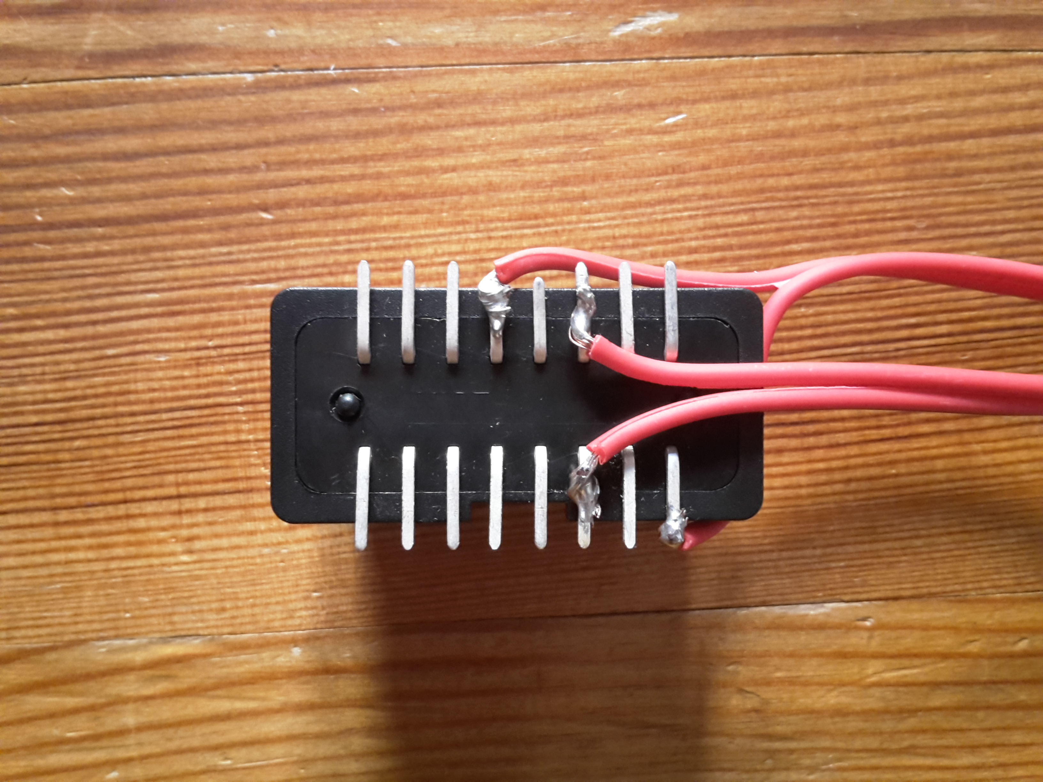
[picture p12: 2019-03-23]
Platine V8/Bilder/OBD-Stecker.jpg

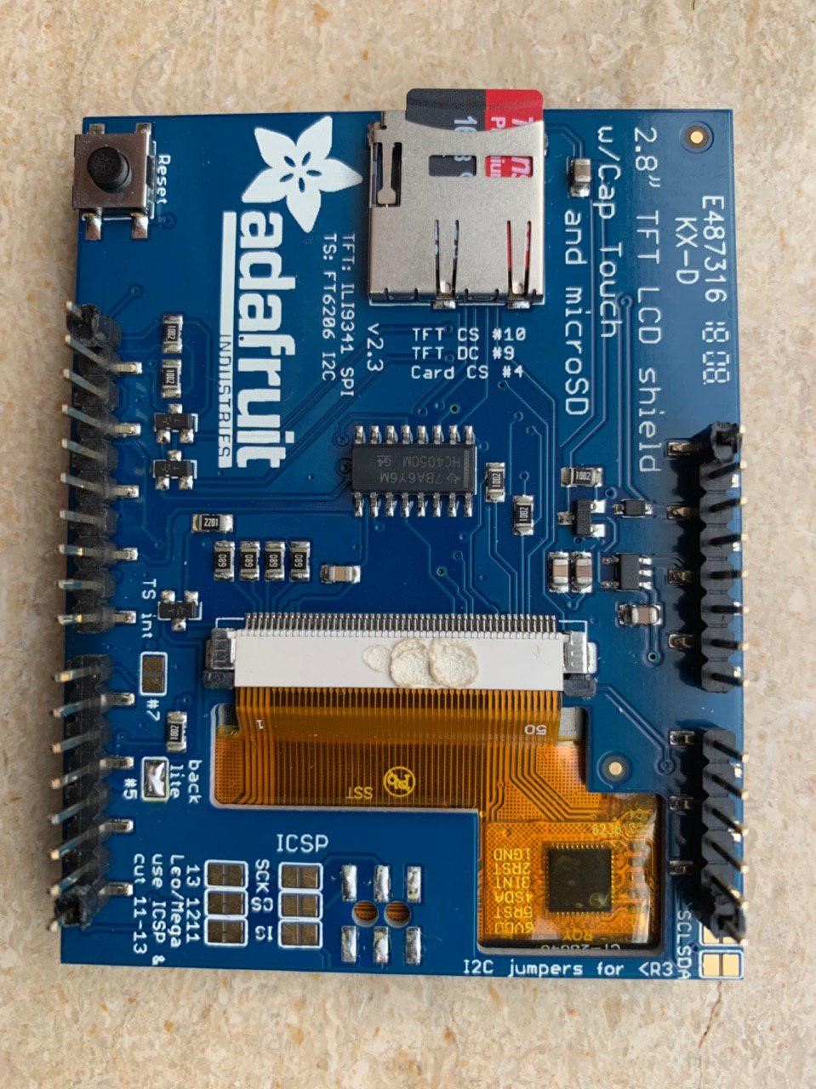
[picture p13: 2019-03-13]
Platine V8/Bilder/Adafruit kapazitives Display alte Version.jpg

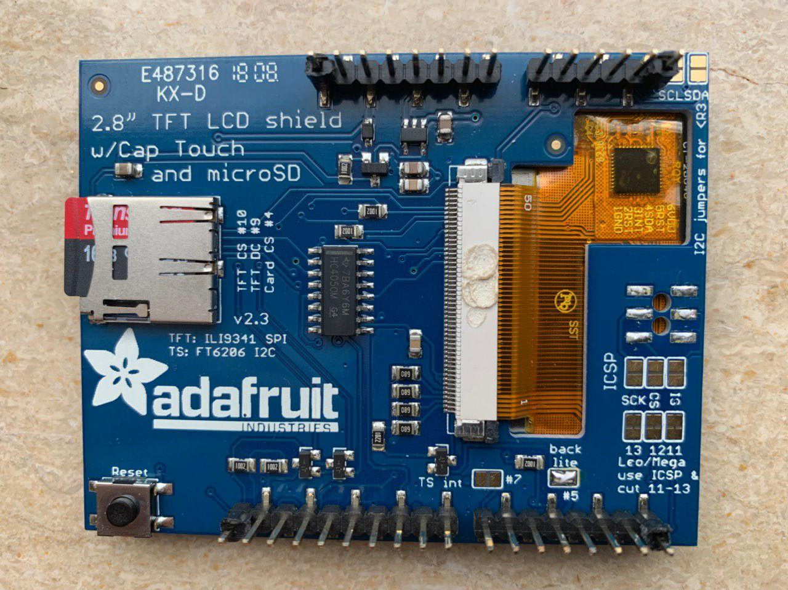
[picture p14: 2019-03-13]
Platine V8/Bilder/Kap-alt.jpg

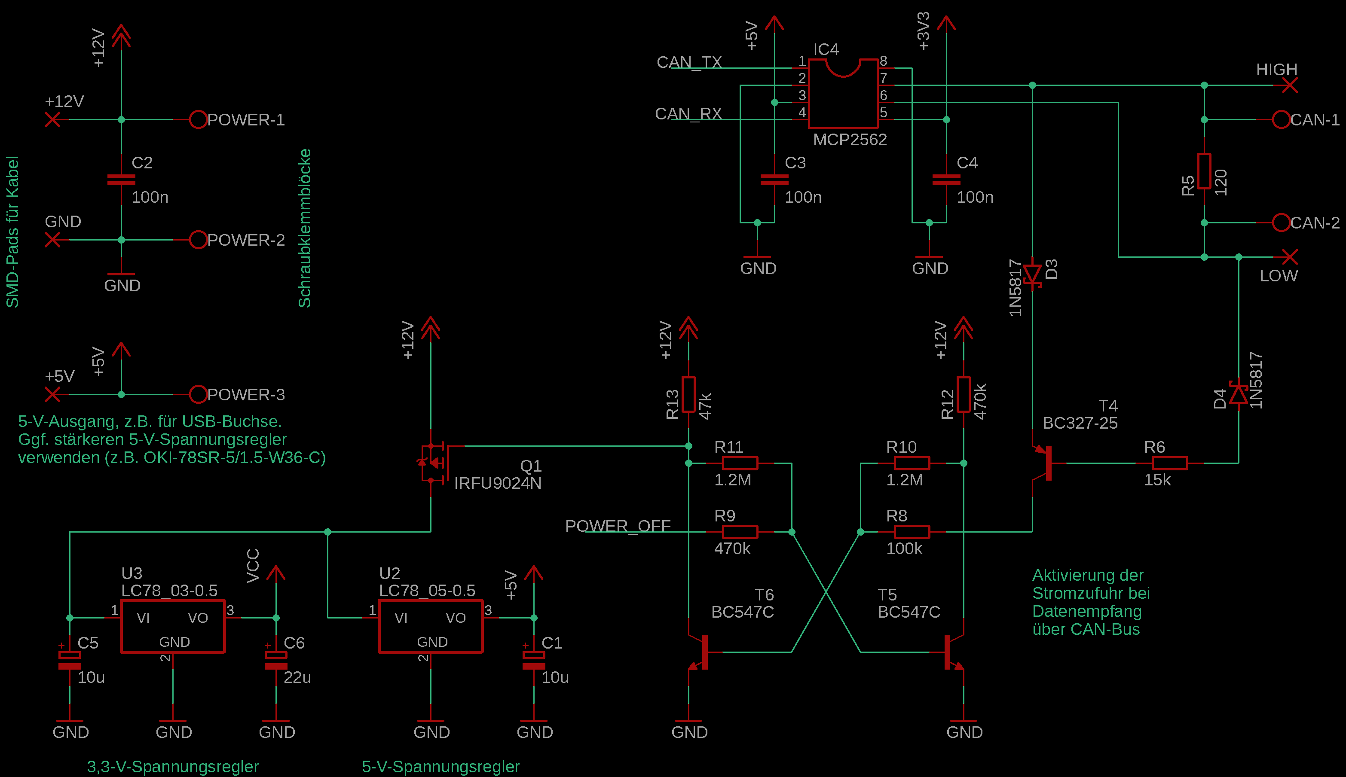
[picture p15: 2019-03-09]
Platine V8/Schaltplan Seite 2.png

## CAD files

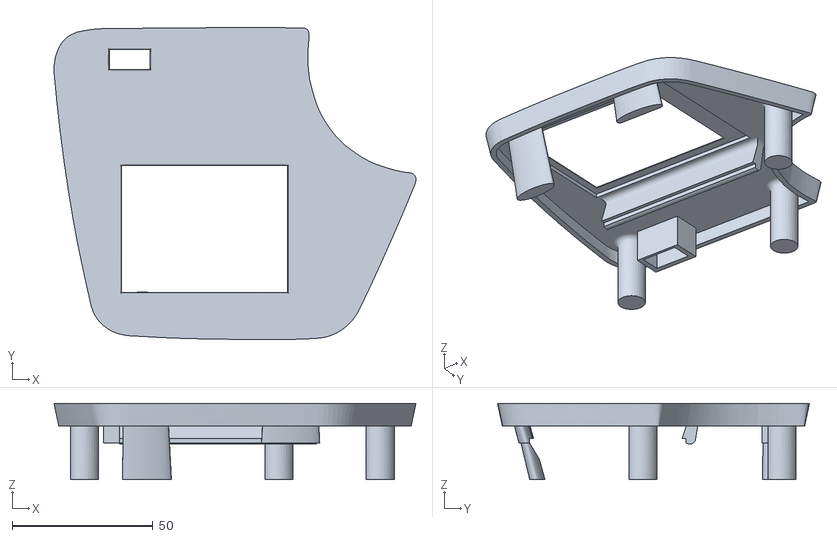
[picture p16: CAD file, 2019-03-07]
3D-Druck/Zoe-Einleger-Kapa-V7.stl
128.6 x 110.8 x 27.0

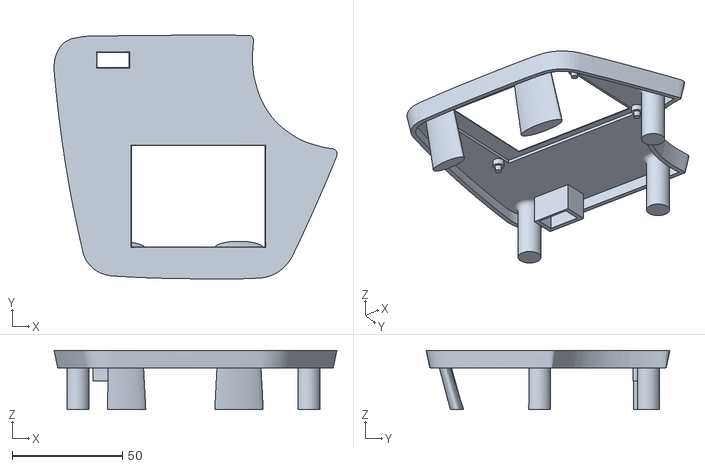
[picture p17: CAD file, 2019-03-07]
3D-Druck/Zoe-Einleger-Resistiv-V7.stl
128.6 x 110.8 x 27.0

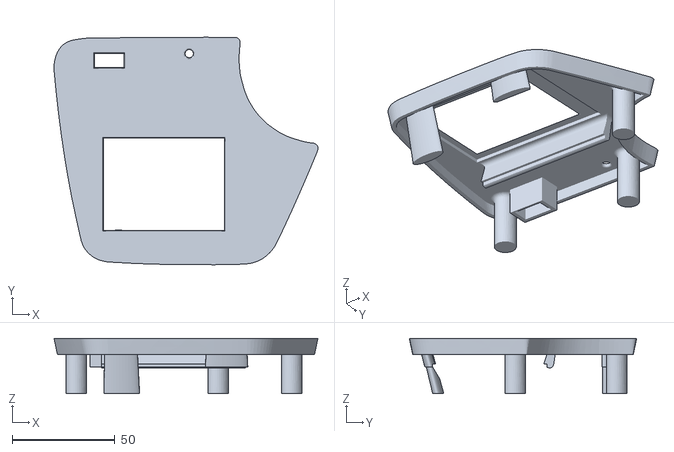
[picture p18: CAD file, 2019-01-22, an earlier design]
3D-Druck/Zoe-Einleger-Kapa-V6.stl
128.6 x 110.8 x 27.0

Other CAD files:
3D-Druck/Zoe-Einleger-Resistiv-V6.stl

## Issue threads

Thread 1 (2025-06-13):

Firmware Sourcecode

CrashOverride2, 2025-06-13:
Bitte mach die Firmware open source sodass auch weitere Fahrzeuge wie die Zoe Ph2 hinzugefügt werden können.

Was ist aktuell der Grund dies nicht zu tun?

kepppfeff, 2025-06-13:
Hallo,
der Entwickler der Firmware hat nicht wirklich etwas mit diesem Github Repo zu tun. Wir waren nur über das GoingElectric Forum in Kontakt. Er war leider nicht bereit, den Quellcode zu veröffentlichen, obwohl mehrere Nutzer ihn damals danach gefragt haben.
Beste Grüße

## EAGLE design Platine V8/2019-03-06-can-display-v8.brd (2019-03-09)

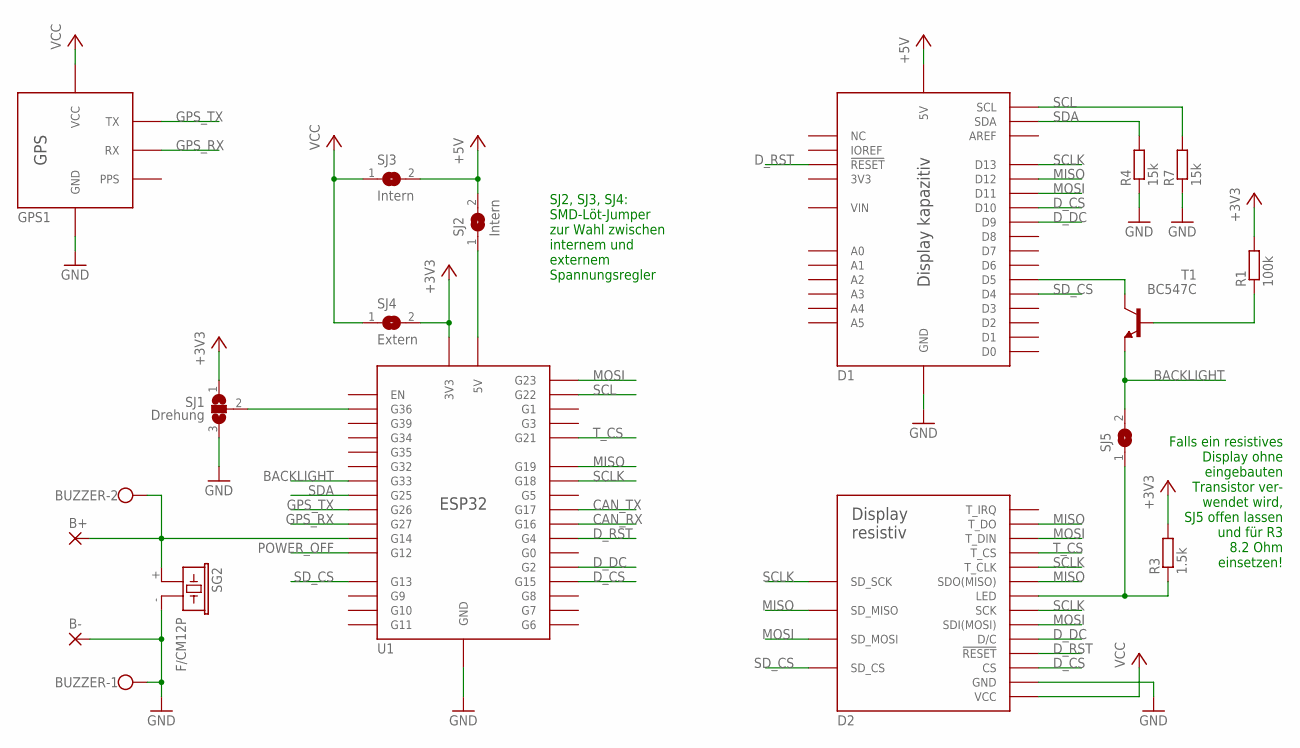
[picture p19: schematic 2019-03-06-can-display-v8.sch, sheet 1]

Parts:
B+: WIREPADSMD5-2,5; 5-2,5
B-: WIREPADSMD5-2,5; 5-2,5
BUZZER: W237-102
D1: TFT-KAPAZITIV
D2: TFT-RESISTIV
GPS1: GPS
R1: 100k; VMTA55
R3: 1.5k; VMTA55
R4, R7: 15k; VMTA55
SG2: F/CM12P
SJ1: Drehung; SJ_2
SJ2, SJ3: Intern; SJ
SJ4: Extern; SJ
SJ5: const.; SJ
T1: BC547C; TO92
U1: ESP32

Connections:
+3V3: R1.2, R3.2, SJ1.1, SJ4.2, U1.3V3, U1.3V3S (3V3); also elsewhere on the board
+5V: D1.5V, SJ2.2, SJ3.2; also elsewhere on the board
BACKLIGHT: SJ5.2, T1.1 (E), U1.G33, U1.G33S (G33)
CAN_RX: U1.G16; also elsewhere on the board
CAN_TX: U1.G17; also elsewhere on the board
D_CS: D1.D10, D2.LCD_CS (CS), U1.G15
D_DC: D1.D9, D2.LCD_DC (D/C), U1.G2
D_RST: D1.RESET (!RESET!), D2.LCD_RESET (!RESET!), U1.G4
GND: B-.1, BUZZER.1, D1.GND@1 (GND), D1.GND@2 (GND), D1.GND@3 (GND), D2.GND, GPS1.GND1 (GND), GPS1.GND2 (GND), R4.1, R7.1, SG2.- (2), SJ1.3, U1.GND@1 (GND), U1.GND@2 (GND), U1.GND@3 (GND), U1.GND@4 (GND); also elsewhere on the board
GPS_RX: GPS1.RX1 (RX), GPS1.RX2 (RX), U1.G27, U1.G27S (G27)
GPS_TX: GPS1.TX1 (TX), GPS1.TX2 (TX), U1.G26, U1.G26S (G26)
MISO: D1.D12, D2.LCD_MISO (SDO(MISO)), D2.SD_MISO, D2.T_DO, U1.G19
MOSI: D1.D11, D2.LCD_MOSI (SDI(MOSI)), D2.SD_MOSI, D2.T_DIN, U1.G23
unnamed: SJ1.2, U1.G36, U1.G36S (G36)
unnamed: D1.D5, T1.3 (C)
unnamed: D2.LED, R3.1, SJ5.1
unnamed: R1.1, T1.2 (B)
unnamed: B+.1, BUZZER.2, SG2.+ (1), U1.G14, U1.G14S (G14)
unnamed: SJ2.1, U1.5V, U1.5VS (5V)
POWER_OFF: U1.G12, U1.G12S (G12); also elsewhere on the board
SCL: D1.KAP_SCL (SCL), R7.2, U1.G22
SCLK: D1.D13, D2.LCD_SCK (SCK), D2.SD_SCK, D2.T_CLK, U1.G18
SDA: D1.KAP_SDA (SDA), R4.2, U1.G25, U1.G25S (G25)
SD_CS: D1.D4, D2.SD_CS, U1.G13, U1.G13S (G13)
T_CS: D2.T_CS, U1.G21
VCC: D2.VCC, GPS1.VCC1 (VCC), GPS1.VCC2 (VCC), SJ3.1, SJ4.1; also elsewhere on the board

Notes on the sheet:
SJ2, SJ3, SJ4: SMD-Löt-Jumper zur Wahl zwischen internem und externem Spannungsregler
Falls ein resistives Display ohne eingebauten Transistor ver- wendet wird, SJ5 offen lassen und für R3 8.2 Ohm einsetzen!

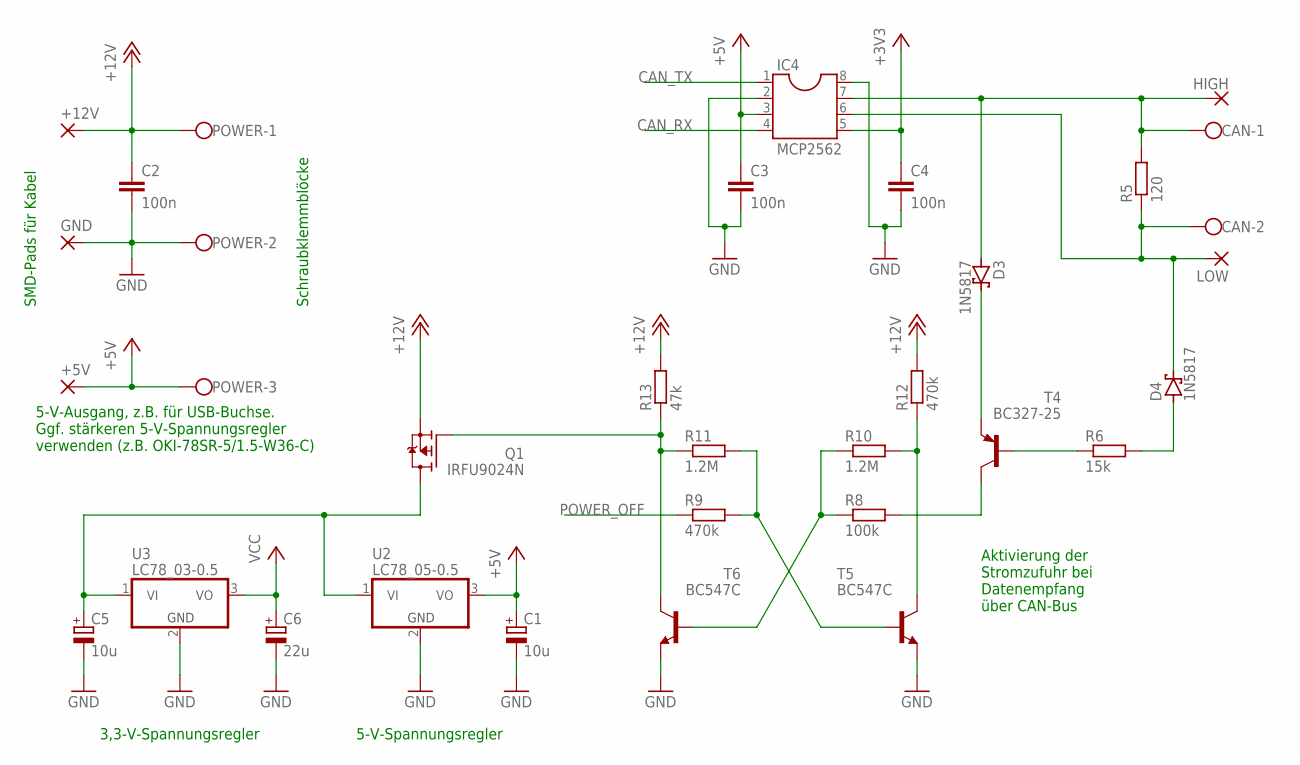
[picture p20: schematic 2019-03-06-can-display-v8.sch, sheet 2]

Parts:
+5V, +12V: WIREPADSMD5-2,5; 5-2,5
C1, C5: 10u; E1,8-4
C2, C3, C4: 100n; C025_050-024X070
C6: 22u; E1,8-4
CAN: W237-102
D3, D4: 1N5817; DO41-7.6
GND: WIREPADSMD5-2,5; 5-2,5
HIGH: WIREPADSMD5-2,5; 5-2,5
IC4: MCP2562; DIL08
LOW: WIREPADSMD5-2,5; 5-2,5
POWER: W237-103
Q1: IRFU9024N; TO251AA-V
R5: 120; VMTA55
R6: 15k; VMTA55
R8: 100k; VMTA55
R9, R12: 470k; VMTA55
R10, R11: 1.2M; VMTA55
R13: 47k; VMTA55
T4: BC327-25; TO92
T5, T6: BC547C; TO92
U2: LC78_05-0.5; SPANNUNGSREGLER
U3: LC78_03-0.5; SPANNUNGSREGLER

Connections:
+3V3: C4.3 (1), IC4.5; also elsewhere on the board
+5V: +5V.1, C1.+, C3.3 (1), IC4.3, POWER.3, U2.3 (VO); also elsewhere on the board
+12V: +12V.1, C2.3 (1), POWER.1, Q1.3 (S), R12.2, R13.2
CAN_RX: IC4.4; also elsewhere on the board
CAN_TX: IC4.1; also elsewhere on the board
GND: C1.-, C2.1 (2), C2.2, C3.1 (2), C3.2, C4.1 (2), C4.2, C5.-, C6.-, GND.1, IC4.2, IC4.8, POWER.2, T5.1 (E), T6.1 (E), U2.2 (GND), U3.2 (GND); also elsewhere on the board
unnamed: D3.C, T4.1 (E)
unnamed: R6.1, T4.2 (B)
unnamed: D4.A, R6.2
unnamed: R8.1, R10.1, T6.2 (B)
unnamed: CAN.1, D3.A, HIGH.1, IC4.7, R5.2
unnamed: CAN.2, D4.C, IC4.6, LOW.1, R5.1
unnamed: R8.2, T4.3 (C)
unnamed: R9.2, R11.2, T5.2 (B)
unnamed: R10.2, R12.1, T5.3 (C)
unnamed: Q1.1 (G), R11.1, R13.1, T6.3 (C)
unnamed: C5.+, Q1.2 (D), U2.1 (VI), U3.1 (VI)
POWER_OFF: R9.1; also elsewhere on the board
VCC: C6.+, U3.3 (VO); also elsewhere on the board

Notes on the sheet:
3,3-V-Spannungsregler
5-V-Spannungsregler
Aktivierung der Stromzufuhr bei Datenempfang über CAN-Bus
SMD-Pads für Kabel
Schraubklemmblöcke
5-V-Ausgang, z.B. für USB-Buchse. Ggf. stärkeren 5-V-Spannungsregler verwenden (z.B. OKI-78SR-5/1.5-W36-C)

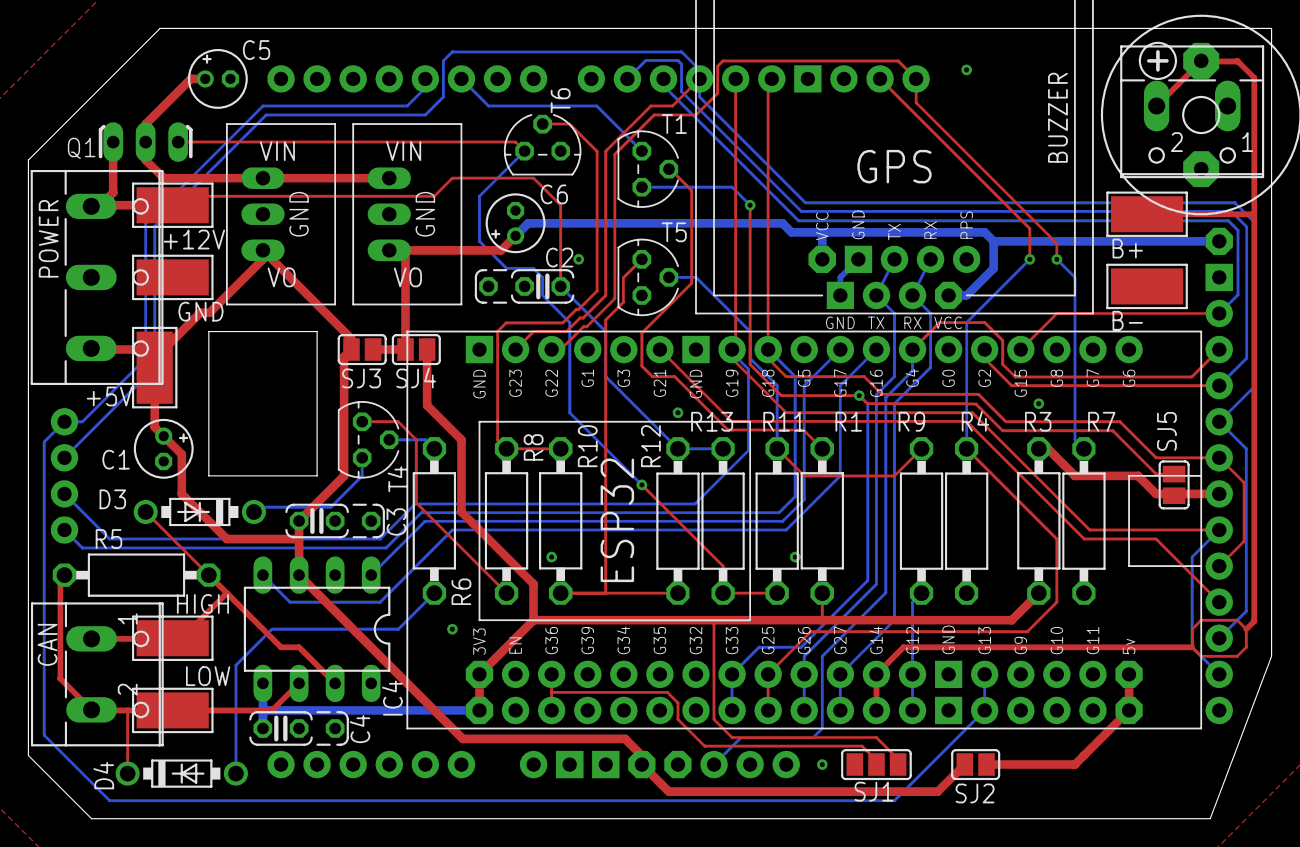
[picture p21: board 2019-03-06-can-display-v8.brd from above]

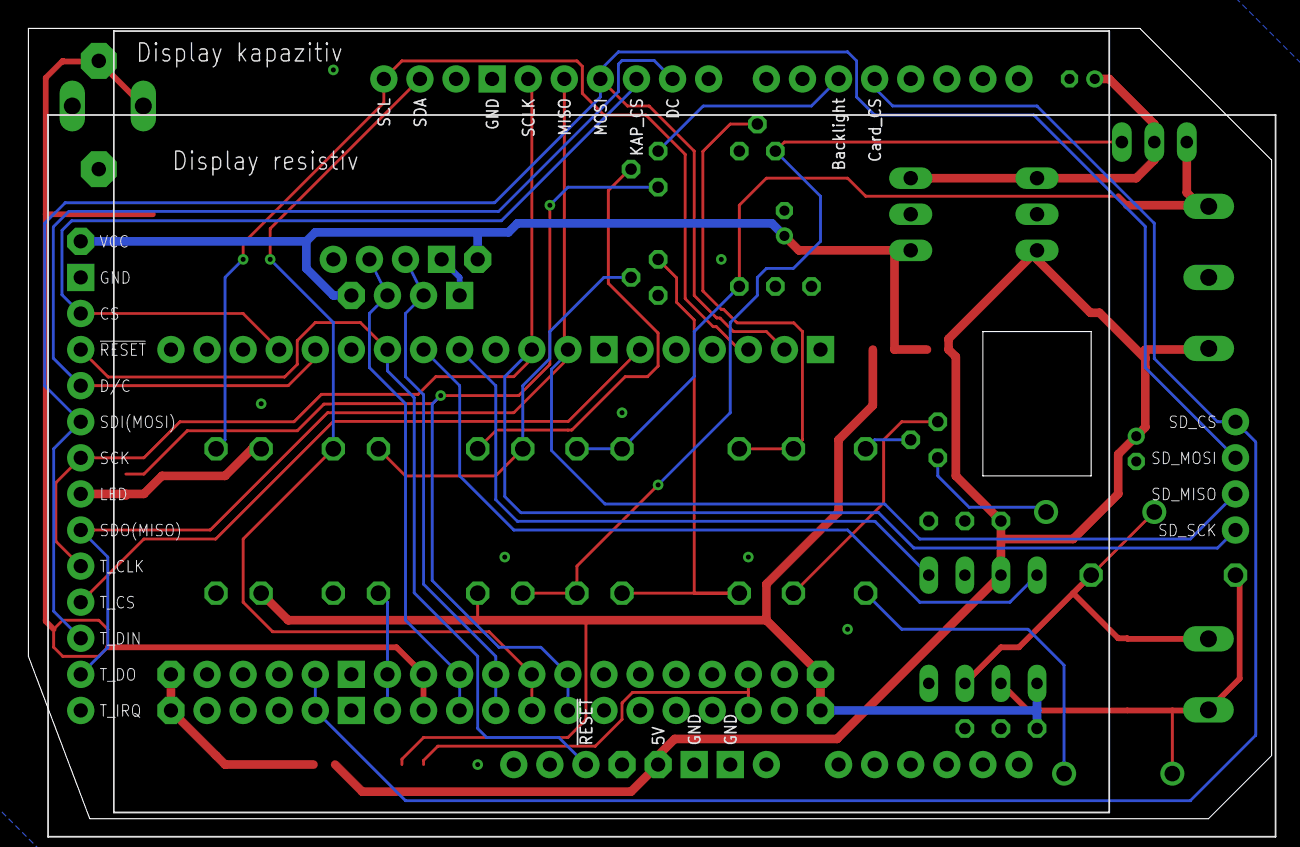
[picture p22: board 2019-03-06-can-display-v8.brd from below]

Board: 2 copper layers, 87.5 x 55.6 mm, 48 parts (2 on the bottom side), 38 nets.

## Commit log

2019-02-26 Move 00-arduino-einstellungen.PNG
2019-02-26 Move 01-esp32-vorbereiten.PNG
2019-02-26 Move CAN-ESP32.SMART.esp32-v2.075.bin
2019-02-26 Move CAN-ESP32.ZOE.esp32-v2.072.bin
2019-02-26 Move CAN-ESP32.ZOE.esp32-v2.075.bin
2019-02-26 Move Zoe-Einleger-Kapa-V6.stl
    [Zoe-Einleger-Kapa-V6.stl]
2019-02-26 Move Zoe-Einleger-Resisitv-V6.stl
    [Zoe-Einleger-Resistiv-V6.stl]
2021-06-29 Add exp-tech link for capacitive touchscreen
